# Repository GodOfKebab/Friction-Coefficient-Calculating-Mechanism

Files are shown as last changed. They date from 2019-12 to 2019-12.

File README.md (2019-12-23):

## A Mechanism That Calculates The Coefficients Of Friction Between Two Surfaces(Yes, both static and kinetic coefficients!)  
  
Honestly, I couldn't find this mechanism a better name. So we will call it the "friction mechanism" throughout the 
readme. Here are some photos 

<p align="center">
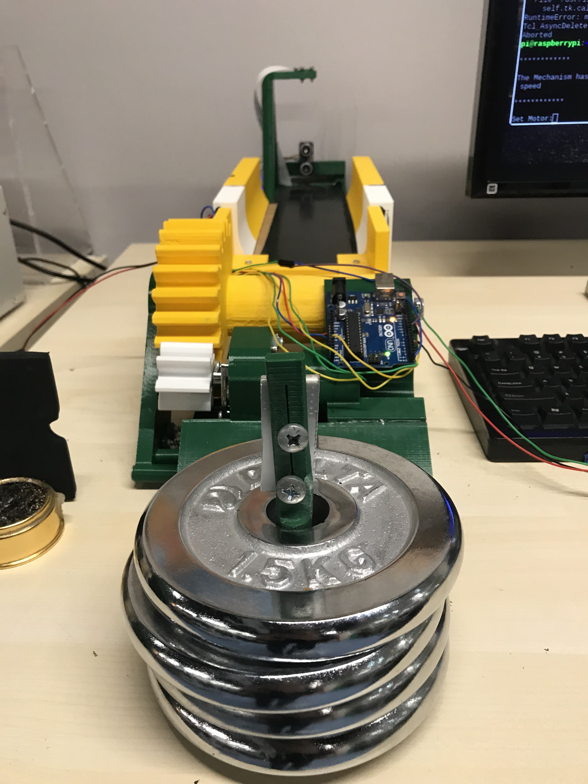
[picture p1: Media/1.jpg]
  
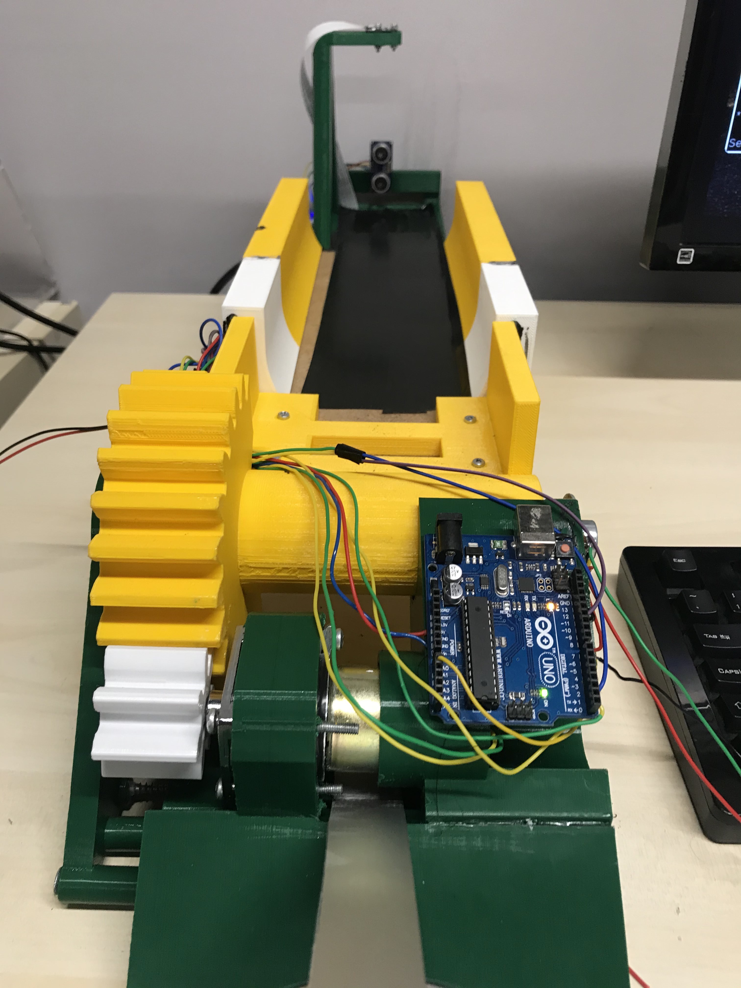
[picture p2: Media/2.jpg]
   
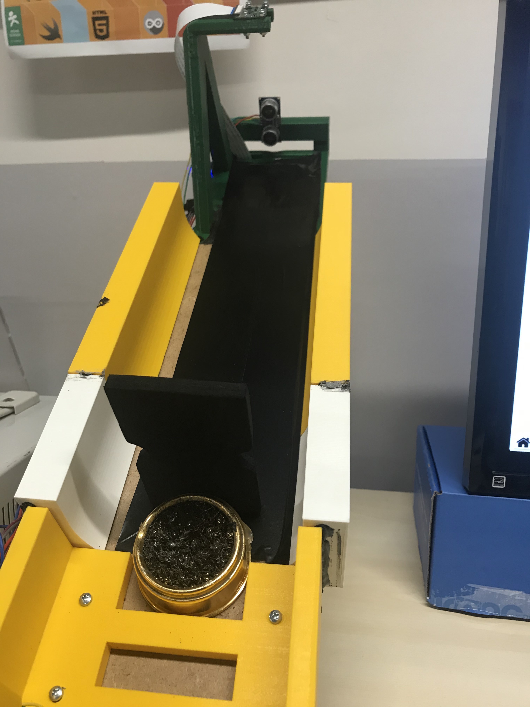
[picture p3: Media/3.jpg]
  
</p>

<p align="center">
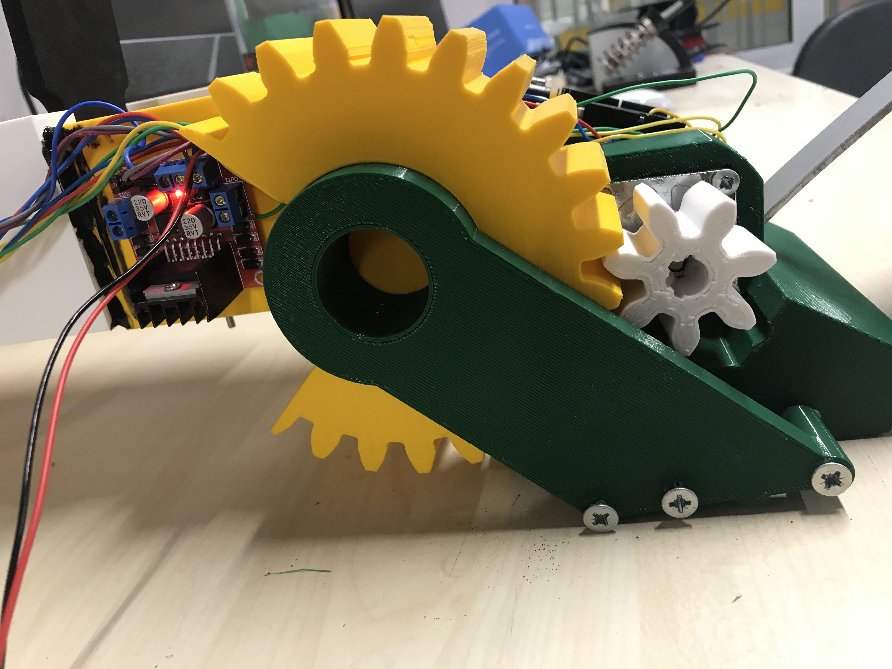
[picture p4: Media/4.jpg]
  
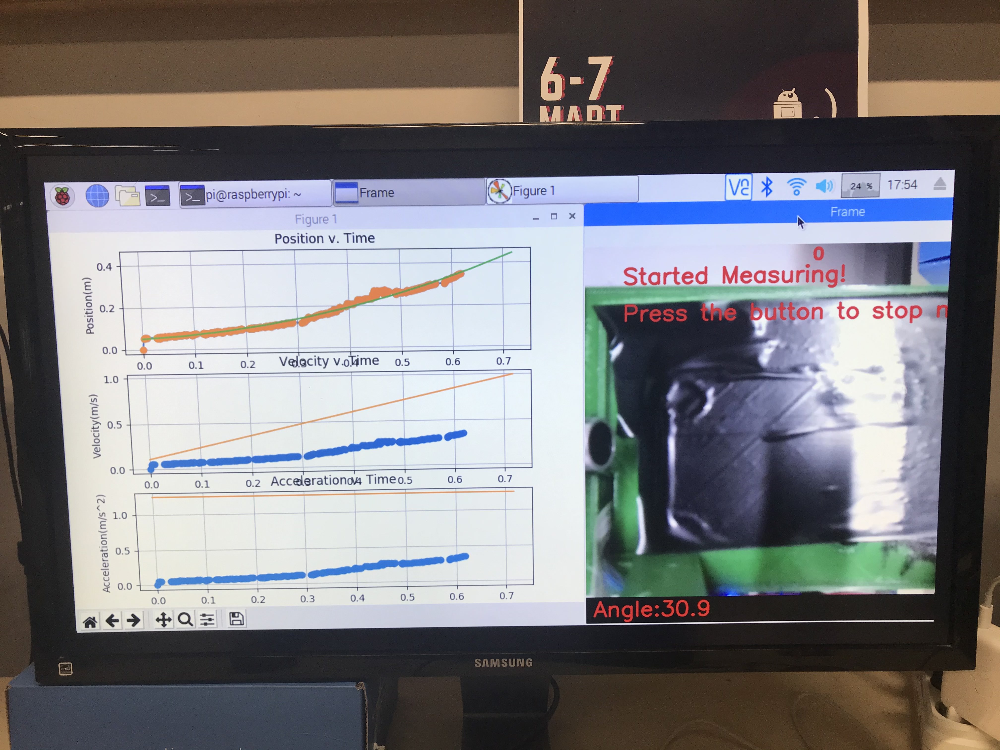
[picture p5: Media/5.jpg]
   
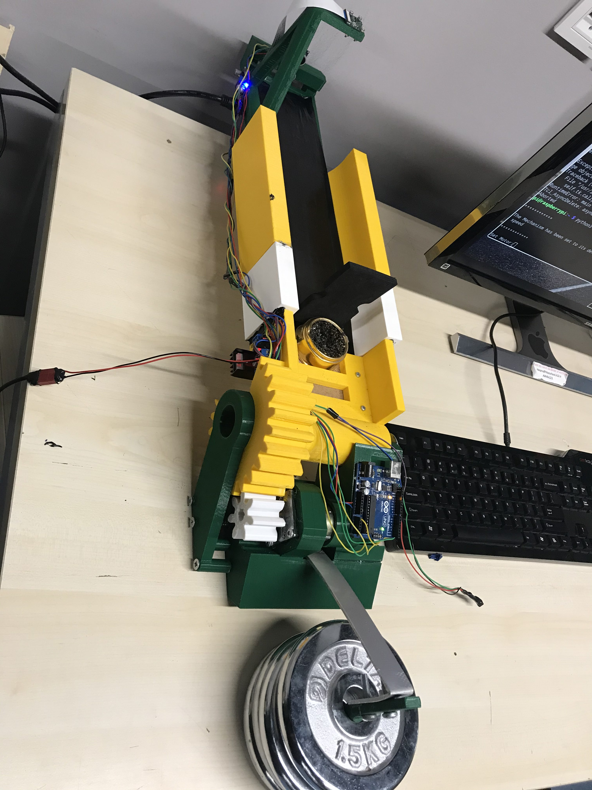
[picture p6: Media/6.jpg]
  
</p>

## Physics Behind This Project

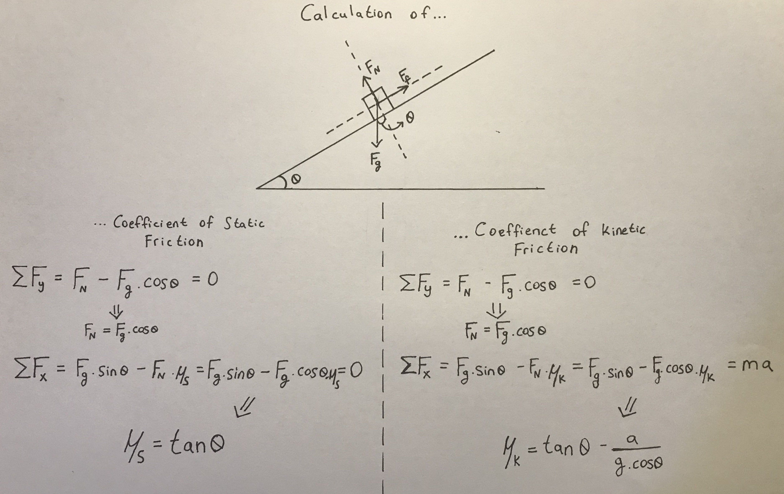
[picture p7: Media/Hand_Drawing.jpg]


The θ is the angle between the inclined surface and the horizontal surface when the object starts to slide.

## How It Works 

This mechanism calculates the coefficients of friction using an inclined surface. It does it by increasing the incline of the 
plane. This is done by a 30 kg-cm torqued motor with a 3D printed 7:24 gears. By using the potentiometer on the other side, 
the program is also aware of the angle with respect to the horizontal surface. 

According to the calculations above, the coefficient of **static** friction is the tangent of the angle measured by the 
inclined surface when the object starts sliding. Therefore to accurately stop and determine this angle, a **Raspberry Pi** and its 
**camera module** is used along with **OpenCV**.

When the program is started with the [mode] set as *static*, the program starts showing the camera feed. From this window,
the user needs to press 's' to select the object to detect a slip. If the selection is done poorly, it can be reset by 
pressing 'r'. 

After this, the user needs to **set the motor speed** to increase the slope. In our mechanism, 45% power is the minimum 
amount of power required to increase the slope. Therefore most of our tests were done around this power level. When the 
program detects a slid after a sufficient increase in slope, the speed is set to 0 and the mechanism calculates and shows 
the **µs** on the screen. 

The **coefficient of kinetic friction**, on the other hand, is calculated in a rather more complicated way. Because according
to the physics of the mechanism above, the µk also requires the **average acceleration** of the object over the course of slide 
down a 40 cm plane. So just like the µs calculation, the mechanism is leveraged until the object starts to slide. However,
to calculate acceleration, an **ultrasonic distance measurement sensor HC-SR04** is used. With this sensor, the position of 
the sliding object is recorded with time stamps. It records until the button connected to Arduino is pressed. Then, the program graphs this data. By fitting the data 
with a second degree polynomial and taking its **first and second derivatives**, the velocity and acceleration graphs are 
generated. Since the acceleration graph is constant, it is used as the magnitude of acceleration used in calculations. 
Finally, with all the data collected(angle and average acceleration), program calculates and shows 
the equations used in graphs and the **µk**.

<p align="center">
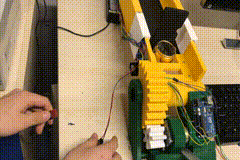
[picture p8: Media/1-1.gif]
  
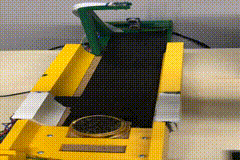
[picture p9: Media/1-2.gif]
   
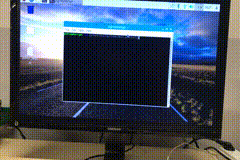
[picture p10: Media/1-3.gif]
  
</p>

<p align="center">
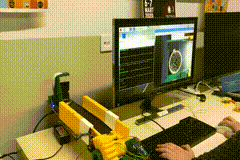
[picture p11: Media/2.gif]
  
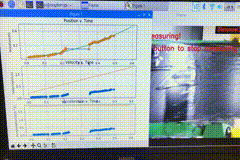
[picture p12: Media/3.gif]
   
</p>

## Usage  
  
You can download this repository and run the code in your system by the following commands.
  
```
git clone https://github.com/GodOfKebab/Friction-Coefficient-Calculating-Mechanism
cd Friction-Coefficient-Calculating-Mechanism/Codes
python3 main.py [mode]
```

There is only one python program named "main.py". However, to run it, you also need to specify the mode: "static" or "kinetic".
This mode determines which coefficient of friction you want to find out. 

## List of Parts

* Raspberry Pi 3B with Pi Camera V2
* 12 V 10 RPM Motor with a maximum torque of 30 kg-cm [[link]](https://www.robotistan.com/12v-42mm-10rpm-reduktorlu-dc-motor)
* L298N Motor Driver Board
* LM2596 Step-Down Voltage Regulator for Raspberry Pi's 5V Power Requirements
* 12V 3A Power Adapter
* HC-SR04
* Arduino Uno for analog potentiometer and button state reading
* Total 6 kg weights to keep the mechanism in balance
* Lots of 3D Printing Material(PLA)

## License
[MIT](https://github.com/GodOfKebab/Friction-Coefficient-Calculating-Mechanism/blob/master/Licence.txt)

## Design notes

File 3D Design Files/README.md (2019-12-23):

## 3D Design Folder

This folder includes the drawings of the mechanism. All of the designing was done in Fusion 360. 
You can see the rendered final image below.

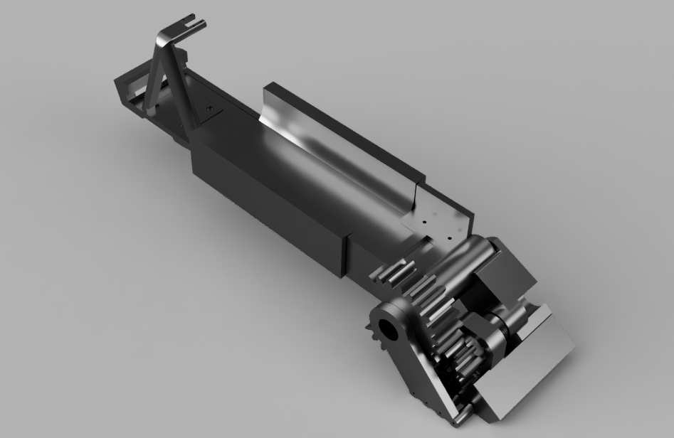
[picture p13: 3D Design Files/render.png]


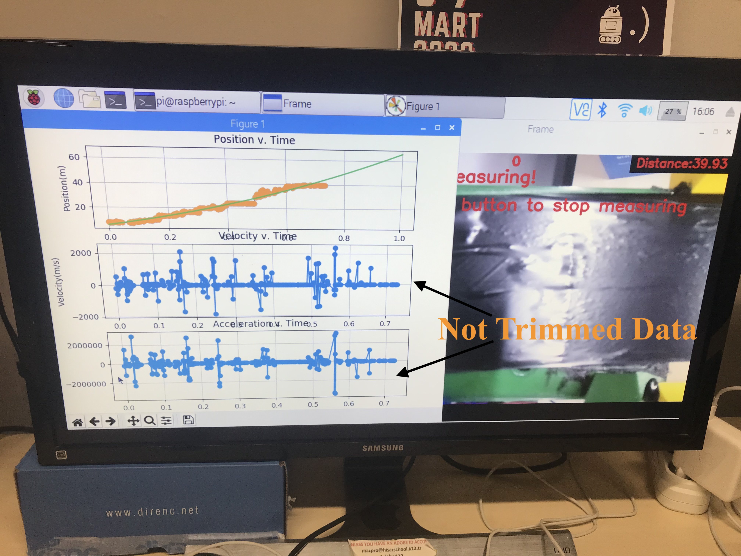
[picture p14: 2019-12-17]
Media/Edited Image 1.jpg

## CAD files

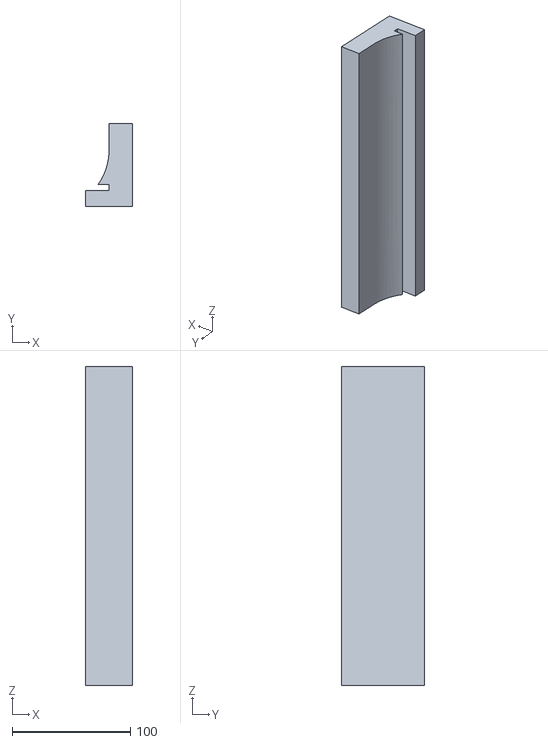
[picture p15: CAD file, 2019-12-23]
3D Design Files/barrier 2.stl
40.0 x 70.0 x 270.0

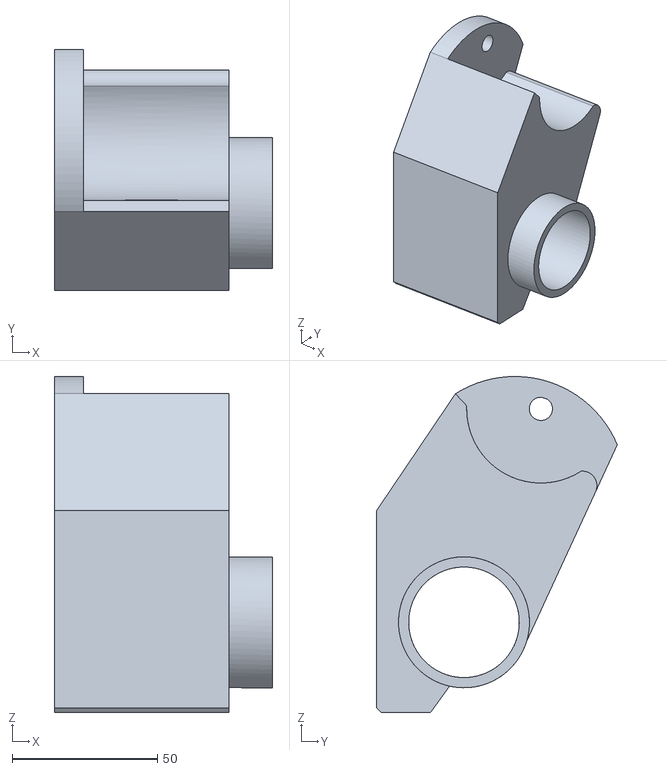
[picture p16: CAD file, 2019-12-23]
3D Design Files/support from the other side.stl
75.0 x 82.7 x 115.5

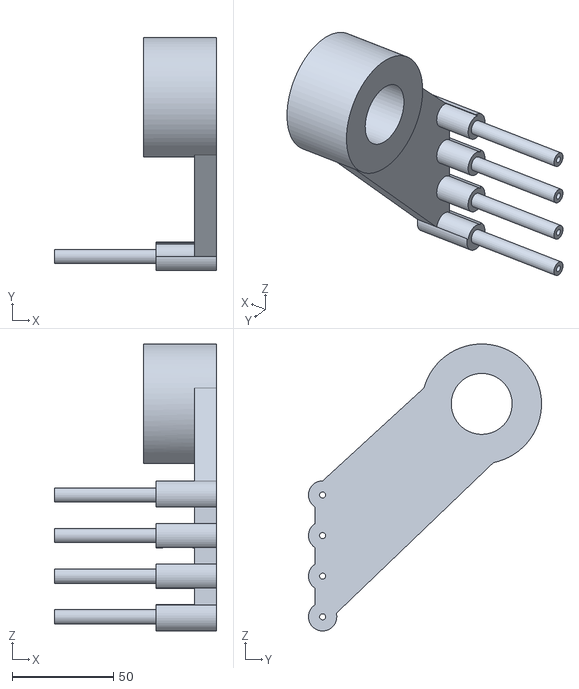
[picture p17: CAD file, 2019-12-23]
3D Design Files/support next to gear.stl
80.0 x 114.8 x 141.4

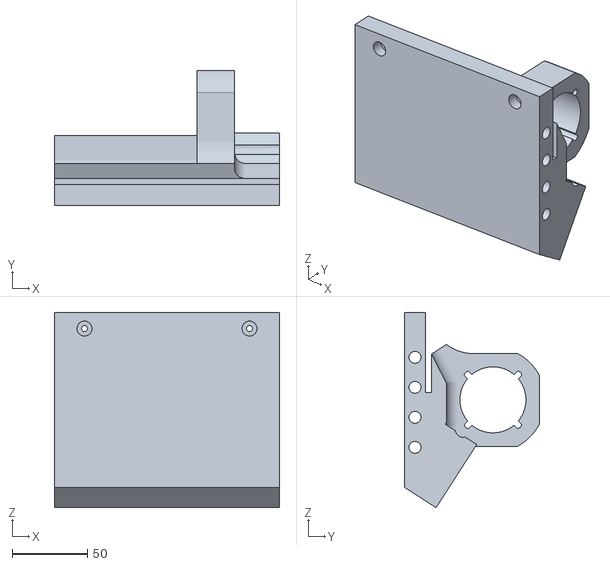
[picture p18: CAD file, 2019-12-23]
3D Design Files/motor holder.stl
150.0 x 89.9 x 130.3

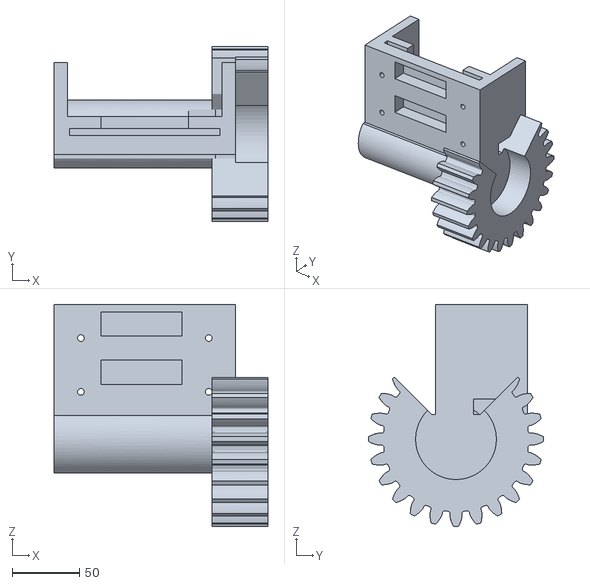
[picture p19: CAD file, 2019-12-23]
3D Design Files/Big Gear with plate connector.stl
159.0 x 130.0 x 165.1

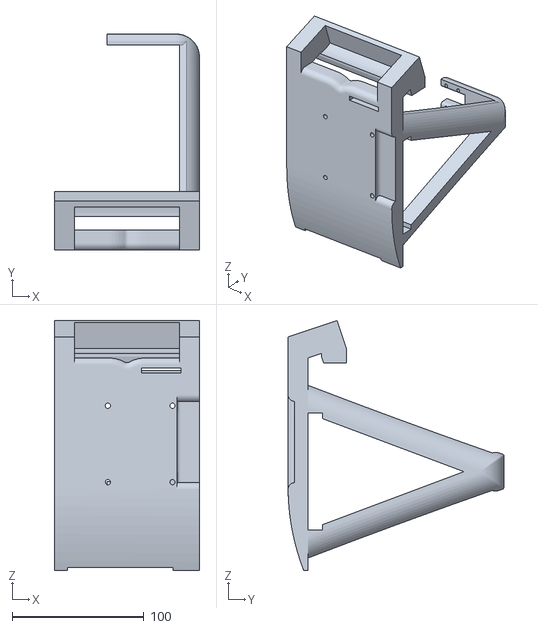
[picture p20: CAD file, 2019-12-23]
3D Design Files/Pi + Camera Holder.stl
110.0 x 163.8 x 189.6

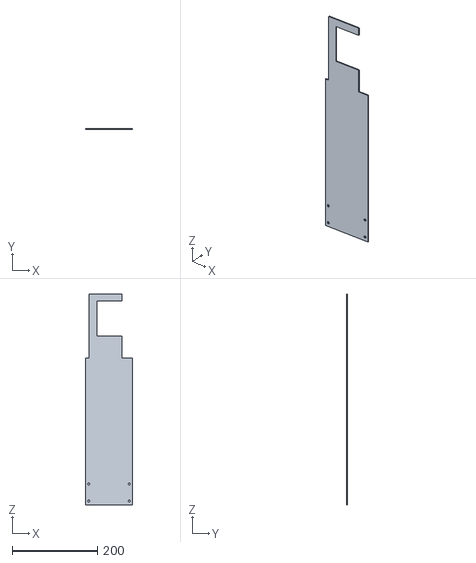
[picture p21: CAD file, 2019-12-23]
3D Design Files/plate.stl
110.0 x 2.15 x 495.1

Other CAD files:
3D Design Files/barrier 1.stl

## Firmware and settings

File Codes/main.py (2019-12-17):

from threading import Thread
from imutils.video import VideoStream
import cv2
import time
import imutils
import math
import argparse
import matplotlib.pyplot as plt
import numpy as np


parser = argparse.ArgumentParser(
    description='This program calculates either the static or kinetic friction coefficient between two surfaces.')
parser.add_argument('mode', type=str, default=None,
                    help='Chose mode. The mode can either be "static" or "kinetic"')

args = parser.parse_args()
mode = args.mode


class Vision(Thread):
    def __init__(self, system):

        super().__init__()

        self.camera = VideoStream(usePiCamera=True, resolution=(688, 528)).start()
        time.sleep(0.5)
        self.tracker = cv2.TrackerMOSSE_create()

        self.isTracking = None
        self.initBB = None
        self.frame = None

        self.initial_target_object_center = None
        self.initial_time = time.time()
        self.moving = False
        self.motion_detected = False
        self.speed = 0

        self.system = system
        self.is_running = True

        self.framesToShow = dict()
        self.isWindowShowEnabled = False
        self.key = "empty"

        self.coefficient_of_static_friction = 0.0
        self.coefficient_of_kinetic_friction = 0.0

    def run(self):
        while self.is_running:
            frame = self.camera.read()

            # Object tracking
            if self.isTracking:
                (success, box) = self.tracker.update(frame)

                if success:
                    (x, y, w, h) = [int(v) for v in box]
                    frame = cv2.rectangle(frame, (x, y), (x + w, y + h), (0, 255, 0), 2)

                    final_target_object_center = (x + w / 2, y + h / 2)
                    self.speed = self.get_speed(final_target_object_center)

                    if self.speed > frame.shape[0] * frame.shape[1] / 100000:
                        self.motion_detected = True
                        self.system.start_recording()
                        self.moving = True
                    else:
                        self.moving = False

            # Arrange the screen
            frame = self.arrange_screen(frame)
            self.showFrame(frame)

        self.isWindowShowEnabled = False
        plt.close()

    # Arrange the general screen
    def arrange_screen(self, frame):
        # General Screen
        frame = cv2.rectangle(frame, (0, 490), (688, 528), (0, 0, 0), -1)
        frame = cv2.rectangle(frame, (510, 0), (688, 30), (0, 0, 0), -1)
        frame = cv2.putText(frame, "Angle:" + str(round(self.system.pot_angle, 1)), (10, 517), cv2.FONT_HERSHEY_SIMPLEX,
                            1, (0, 0, 200), 2, cv2.LINE_AA)
        frame = cv2.putText(frame, "Distance:" + str(round(self.system.sonar, 2)), (520, 20), cv2.FONT_HERSHEY_SIMPLEX,
                            0.7, (0, 0, 200), 2, cv2.LINE_AA)

        # Custom Screen Settings
        if mode == "static":
            frame = self.arrange_screen_static(frame)
        elif mode == "kinetic":
            frame = self.arrange_screen_kinetic(frame)
        else:
            raise Exception("Wrong mode selected. Please Specify the mode as either 'static' or 'kinetic'")

        return frame

    # Specialize arrange_screen for static friction calculations
    def arrange_screen_static(self, frame):

        if self.moving:
            frame = cv2.putText(frame, "Moved!", (50, 50), cv2.FONT_HERSHEY_SIMPLEX, 1.0, (0, 0, 200), 2, cv2.LINE_AA)
            self.coefficient_of_static_friction = round(math.tan(math.pi * self.system.pot_angle / 180.0), 2)

        if self.motion_detected:
            frame = cv2.putText(frame, "coefficient of static friction:" + str(self.coefficient_of_static_friction),
                                (300, 517), cv2.FONT_HERSHEY_SIMPLEX, 0.75, (0, 0, 200), 1, cv2.LINE_AA)

        return frame

    # Specialize arrange_screen for kinetic friction calculations
    def arrange_screen_kinetic(self, frame):

        if self.motion_detected:
            frame = cv2.putText(frame, "Started Measuring!", (50, 50), cv2.FONT_HERSHEY_SIMPLEX, 1.0, (0, 0, 200), 2,
                                cv2.LINE_AA)
            frame = cv2.putText(frame, "Press the button to stop measuring", (50, 100), cv2.FONT_HERSHEY_SIMPLEX, 1.0,
                                (0, 0, 200), 2, cv2.LINE_AA)

        if self.moving:
            self.system.set_motor_speed(0)

        # End reading data
        if self.system.button_state and len(self.system.recorded_data) > 10:
            # Stop mechanism
            self.system.set_motor_speed(0)
            self.motion_detected = False

            # Process the recorded data
            data = self.system.end_recording_data()

            x = list()
            y = list()
            for i in data:
                x.append(i["time_stamp"])
                y.append(i["distance"] / 100.0)

            p = plotter()
            position_v_time = [x, y]
            position_v_time = p.trim_data(position_v_time)
            p.plot("Position", position_v_time)

            position_v_time_eq = p.plot_equation("Position", position_v_time)
            velocity_v_time_eq = p.take_derivative(position_v_time_eq)
            acceleration_v_time_eq = p.take_derivative(velocity_v_time_eq)

            _ = p.plot_equation("Velocity", position_v_time, eq=velocity_v_time_eq)
            _ = p.plot_equation("Acceleration", position_v_time, eq=acceleration_v_time_eq)

            print("\n\n*********************")
            print("Position vs. Time Graph's Equation is:")
            print(position_v_time_eq)
            print("\n*********************")
            print("Velocity vs. Time Graph's Equation is:", velocity_v_time_eq)
            print("*********************")
            print("Acceleration vs. Time Graph's Equation is:", acceleration_v_time_eq, "\n", "*********************")

            coefficient_of_static_friction = round(math.tan(math.pi * self.system.pot_angle / 180.0), 2) - float(acceleration_v_time_eq.c[0]) / (9.81 * round(math.cos(math.pi * self.system.pot_angle / 180.0), 2))

            print("Therefore the coefficient of kinetic friction is:{}".format(coefficient_of_static_friction))

            p.show()

        return frame

    # Multi-threaded window showing function
    def showFrame(self, frameToShow, windowName="Frame"):

        self.framesToShow[windowName] = frameToShow

        if not self.isWindowShowEnabled:
            self.isWindowShowEnabled = True
            Thread(target=self.__updateWindowFrame__, args=()).start()

    # Thread for updating the frame
    def __updateWindowFrame__(self):

        while self.isWindowShowEnabled:

            for name in self.framesToShow.copy():
                cv2.imshow(name, self.framesToShow[name])

            self.key = cv2.waitKey(30)

            if self.key == ord("s"):
                initBB = cv2.selectROI("Frame", self.framesToShow["Frame"], fromCenter=False, showCrosshair=True)
                self.tracker.init(self.framesToShow["Frame"], initBB)
                self.isTracking = True

            if self.key == ord('r'):
                self.motion_detected = False
                self.tracker = cv2.TrackerMOSSE_create()
                self.isTracking = False
                self.system.enabled_recording = False
                self.system.recorded_data = list()

        cv2.destroyAllWindows()

    # Calculate the velocity(pixel/seconds) of the selected object
    def get_speed(self, target_center):
        elapsed = time.time() - self.initial_time

        if self.initial_target_object_center is None:
            self.initial_target_object_center = target_center
            speed = 0
        else:
            displacement = ((target_center[0] - self.initial_target_object_center[0]) ** 2 +
                            (target_center[1] - self.initial_target_object_center[1]) ** 2) ** 0.5
            speed = displacement / elapsed

        self.initial_time = time.time()
        self.initial_target_object_center = target_center
        return speed


class plotter:
    def __init__(self):
        self.fig, (ax1, ax2, ax3) = plt.subplots(3, 1, figsize=(7, 8))
        plt.subplots_adjust(top=0.95, bottom=0.05)

        ax1.set_title("Position v. Time")
        ax1.set_xlabel("Time(s)")
        ax1.set_xlim(left=0.0)
        ax1.set_ylabel("Position(m)")
        ax1.set_ylim(bottom=0.0)
        ax1.grid(True)
        ax1.autoscale(True)

        ax2.set_title("Velocity v. Time")
        ax2.set_xlabel("Time(s)")
        ax2.set_xlim(left=0.0)
        ax2.set_ylabel("Velocity(m/s)")
        ax2.set_ylim(bottom=0.0)
        ax2.grid(True)
        ax2.autoscale(True)

        ax3.set_title("Acceleration v. Time")
        ax3.set_xlabel("Time(s)")
        ax3.set_xlim(left=0.0)
        ax3.set_ylabel("Acceleration(m/s^2)")
        ax3.set_ylim(bottom=0.0)
        ax3.grid(True)
        ax3.autoscale(True)

        self.ax = {
            "Position": ax1,
            "Velocity": ax2,
            "Acceleration": ax3
        }

    def take_derivative(self, eq):

        # second degree polynomial
        if len(eq.c) == 3:
            new_eq = eq.deriv()

        elif len(eq.c) == 2:
            new_eq = eq.deriv()

        else:
            raise Exception("Your equation must be either of 1st or 2nd degree")

        return new_eq

    def trim_data(self, data):
        x = data[0]
        y = data[1]

        new_x = list()
        new_y = list()

        for t in range(0, len(y)):
            x[t] = x[t] - (x[0] + x[1] + x[2] + x[3] + x[4] + x[5] + x[6] + x[7] + x[8] + x[9])/10.0
            y[t] = y[t] - (y[0] + y[1] + y[2] + y[3] + y[4] + y[5] + y[6] + y[7] + y[8] + y[9])/10.0

        for t, pos in enumerate(y):
            if pos < 0.35 and pos > 0.03:
                new_x.append(x[t])
                new_y.append(pos)



        return [new_x, new_y]


    def plot(self, graph_of, plot_data):
        self.ax[graph_of].plot(plot_data[0], plot_data[1], **{"marker": "o"})

    def plot_equation(self, graph_of, data_lists, eq=None):
        x = data_lists[0]
        y = data_lists[1]

        t = np.linspace(0, x[-1] + 0.1, y[-1] + 10)

        if graph_of == "Position":
            p_pos = np.poly1d(np.polyfit(x, y, 2))

        elif graph_of == "Velocity" or graph_of == "Acceleration":
            p_pos = eq

        else:
            raise Exception("You can only plot Position, Velocity or Acceleration")

        self.ax[graph_of].plot(x, y, 'o', t, p_pos(t), '-')

        return p_pos

    def show(self):
        plt.show()


from RpiMotorLib import rpi_dc_lib
from RPi import GPIO


class InclinedSurface(Thread):
    def __init__(self):
        super().__init__()
        self.motor = rpi_dc_lib.L298NMDc(19, 13, 26, 50)

        self.pot_angle = 0.0
        self.sonar = 0
        self.button_state = False
        self.is_running = True

        self.recorded_data = list()
        self.enabled_recording = False

        self.percent = 0

    def run(self):
        import serial  # Import Serial Library

        arduinoSerialData = serial.Serial('/dev/ttyS0', 57600)  # Create Serial port object called arduinoSerialData

        while self.is_running:
            try:
                my_data = arduinoSerialData.readline()
                str_my_data = str(my_data, encoding="utf-8").split("\r\n")[0]
                list_my_data = str_my_data.split(",")

                pot = int(list_my_data[0])
                self.pot_angle = -0.257 * pot + 219.0

                sonar = float(list_my_data[1])
                self.sonar = sonar if sonar < 40 else self.sonar

                self.button_state = int(list_my_data[2])

                if self.enabled_recording:
                    measurement = {"angle": self.pot_angle,
                                   "distance": self.sonar,
                                   "time_stamp": time.time()}

                    self.recorded_data.append(measurement)

                if self.percent > 0:
                    self.motor.backward(self.percent)
                elif self.percent < 0:
                    self.motor.forward(-self.percent)
                else:
                    self.motor.stop(0)

                if not (-7 < self.pot_angle < 60):
                    self.percent = 0

            except:
                pass

    def start_recording(self):
        self.enabled_recording = True

    def end_recording_data(self):
        self.enabled_recording = False

        initial_time = self.recorded_data[0]["time_stamp"]
        for index in range(len(self.recorded_data)):
            self.recorded_data[index]["time_stamp"] = self.recorded_data[index]["time_stamp"] - initial_time

        return self.recorded_data

    def set_motor_speed(self, percent):
        self.percent = percent

    def get_to_starting_point(self):

        if self.pot_angle > 0:
            while self.pot_angle > 0:
                self.set_motor_speed(-50)
                time.sleep(0.01)
        else:
            while self.pot_angle < 0:
                self.set_motor_speed(50)
                time.sleep(0.01)

        self.set_motor_speed(0)
        print("\n************\n")
        print("The Mechanism has been set to its default position. Ready to set motor speed")
        print("\n************\n")


system = InclinedSurface()
system.start()

vis = Vision(system)
vis.start()

system.get_to_starting_point()


while True:
    try:
        val = input("Set Motor:")
        try:
            if val == "default":
                system.get_to_starting_point()
            else:
                system.set_motor_speed(int(val))
        except:
            print("\nOnly decimal numbers allowed!\n")

    except KeyboardInterrupt:
        print("\nexiting\n")
        system.is_running = False
        vis.is_running = False
        system.set_motor_speed(0)
        time.sleep(0.5)
        exit()
